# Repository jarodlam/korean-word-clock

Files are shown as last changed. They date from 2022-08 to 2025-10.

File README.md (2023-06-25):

# Korean word clock
A wall-mounted clock that reads out the current time in Korean.

## Bill of materials
* Raspberry Pi Pico
    * [Core Electronics](https://core-electronics.com.au/raspberry-pi-pico.html)
* Pimoroni RV3028 Breakout
    * [Core Electronics](https://core-electronics.com.au/pimoroni-rv3028-real-time-clock-rtc-breakout.html)
* Adafruit USB-C Breakout
    * [Core Electronics](https://core-electronics.com.au/adafruit-usb-c-breakout-board-downstream-connection.html)
* 1000 uF electrolytic capacitor
    * [Core Electronics](https://core-electronics.com.au/electrolytic-decoupling-capacitors-1000uf-25v.html)
* 1N4733A 5.1 V Zener diode
    * [Core Electronics](https://core-electronics.com.au/zener-diode-5-1v-1w.html)
    * [Jaycar](https://www.jaycar.com.au/5-1v-1n4733-1-watt-zener-diode/p/ZR1403)
* LED 3-pin JST-SM pigtail connectors
    * [Core Electronics](https://core-electronics.com.au/led-strip-pigtail-connector-3-pin.html)
* 12mm momentary push button
    * [Core Electronics](https://core-electronics.com.au/momentary-push-button-switch-12mm-square.html)
    * [Jaycar](https://www.jaycar.com.au/spst-pcb-mount-tactile-switch-round/p/SP0609)

## Translations
Korean | English
------ | -------
한시 | one o'clock
두시 | two o'clock
세시 | three o'clock
네시 | four o'clock
다섯시 | five o'clock
여섯시 | six o'clock
일곱시 | seven o'clock
여덟시 | eight o'clock
아홉시 | nine o'clock
열시 | ten o'clock
열한시 | eleven o'clock
열두시 | twelve o'clock
자정 | midnight
정오 | noon
오분 | five minutes
십분 | ten minutes
이십분 | twenty minutes
삼십분 | thirty minutes
사십분 | forty minutes
오십분 | fifty minutes

## Acknowledgements
* [HangulClock](https://suapapa.github.io/site-hangulclocks/) by Homin Lee
* [Raspberry Pi Pico EAGLE library](https://github.com/Lobo-T/RPI-Pico-Eagle-lib) by Lobo-T
* [pi_pico_neopixel](https://github.com/blaz-r/pi_pico_neopixel) MicroPython library by Blaž Rolih
* [rv3028-python](https://github.com/pimoroni/rv3028-python) MicroPython library by Pimoroni

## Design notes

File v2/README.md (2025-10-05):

# Korean word clock v2
A wall-mounted clock that reads out the current time in Korean.

Change log from v1:
- Uses an ATmega32U4 microcontroller instead of the RP2040. 
- PCB is drawn in KiCad instead of EAGLE.

## Bill of materials
* SparkFun Qwiic Pro Micro
    * [Core Electronics](https://core-electronics.com.au/sparkfun-qwiic-pro-micro-usb-c-atmega32u4.html)
    * [Mouser](https://au.mouser.com/ProductDetail/SparkFun/DEV-15795?qs=vHuUswq2%252BszUNhUhTg0rsg%3D%3D)
* Pimoroni RV3028 Breakout
    * [Core Electronics](https://core-electronics.com.au/pimoroni-rv3028-real-time-clock-rtc-breakout.html)
    * [Mouser](https://au.mouser.com/ProductDetail/Pimoroni/PIM449?qs=GedFDFLaBXE4W0MVwPUjCA%3D%3D)
* LED 3-pin JST-SM pigtail connector
    * [Core Electronics](https://core-electronics.com.au/led-strip-pigtail-connector-3-pin.html)
    * [Mouser](https://au.mouser.com/ProductDetail/Adafruit/1663?qs=GURawfaeGuBbzkAfeSrhnA%3D%3D)
* 12mm momentary push buttons
    * [Core Electronics](https://core-electronics.com.au/momentary-push-button-switch-12mm-square.html)
    * [Mouser](https://au.mouser.com/ProductDetail/SparkFun/COM-09190?qs=WyAARYrbSnYmfgv9mXV0oQ%3D%3D)
    * [Jaycar](https://www.jaycar.com.au/spst-pcb-mount-tactile-switch-round/p/SP0609)
* 4.7k resistors 1.6x3.6 mm
    * [Mouser](https://au.mouser.com/ProductDetail/YAGEO/MFR25SFTF52-4K7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)

## Software

Requirements:

- [PlatformIO](https://platformio.org/)

Usage (run from `src/` directory with `platformio.ini`:

```sh
# Build
$ pio run

# Upload
$ pio run -t upload

# Generate clangd compile_commands.json for LSP
$ pio run -t compiledb -e sparkfun_promicro16

# Clean build files
$ pio run -t clean

# Run local tests
$ pio test -e native

# View serial monitor
$ pio device monitor
```

## Translations
Korean | English
------ | -------
한시 | one o'clock
두시 | two o'clock
세시 | three o'clock
네시 | four o'clock
다섯시 | five o'clock
여섯시 | six o'clock
일곱시 | seven o'clock
여덟시 | eight o'clock
아홉시 | nine o'clock
열시 | ten o'clock
열한시 | eleven o'clock
열두시 | twelve o'clock
자정 | midnight
정오 | noon
오분 | five minutes
십분 | ten minutes
이십분 | twenty minutes
삼십분 | thirty minutes
사십분 | forty minutes
오십분 | fifty minutes

## Acknowledgements and references
* [HangulClock](https://suapapa.github.io/site-hangulclocks/) by Homin Lee
* [Adafruit NeoPixel library](https://github.com/adafruit/Adafruit_NeoPixel)
* [SparkFun KiCad Libraries](https://github.com/sparkfun/SparkFun-KiCad-Libraries)

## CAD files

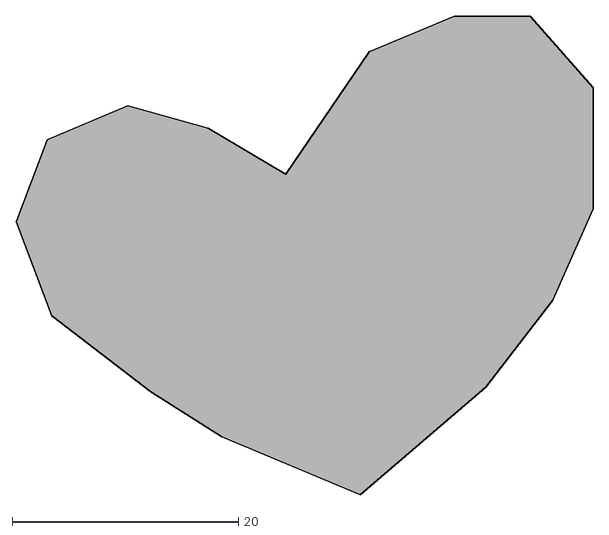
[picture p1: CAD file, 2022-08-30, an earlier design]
v1/pcb/heart.dxf
51.0 x 42.3

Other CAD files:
v1/cad/main.scad

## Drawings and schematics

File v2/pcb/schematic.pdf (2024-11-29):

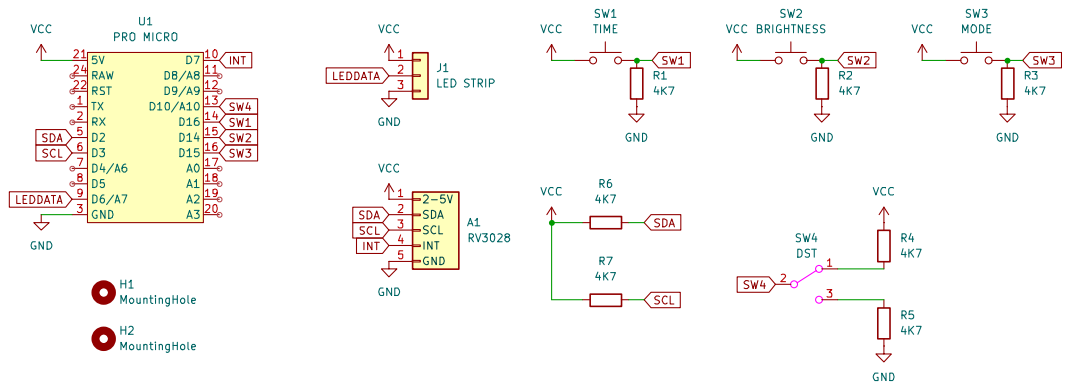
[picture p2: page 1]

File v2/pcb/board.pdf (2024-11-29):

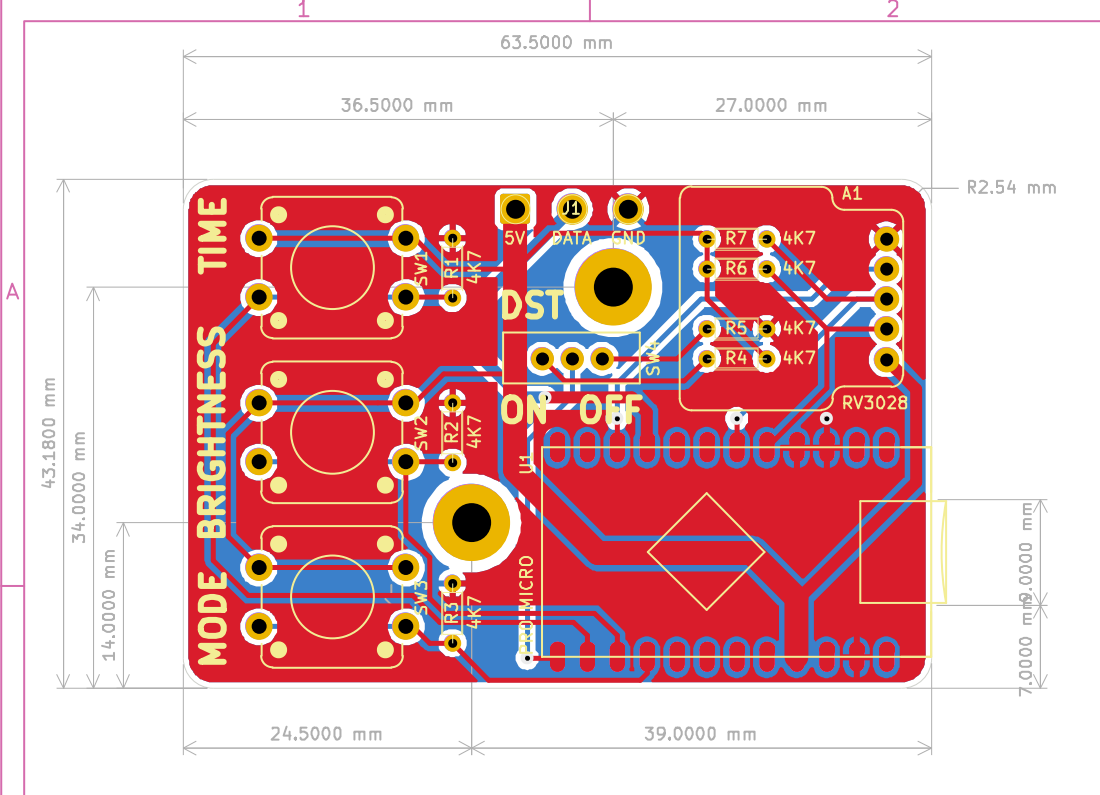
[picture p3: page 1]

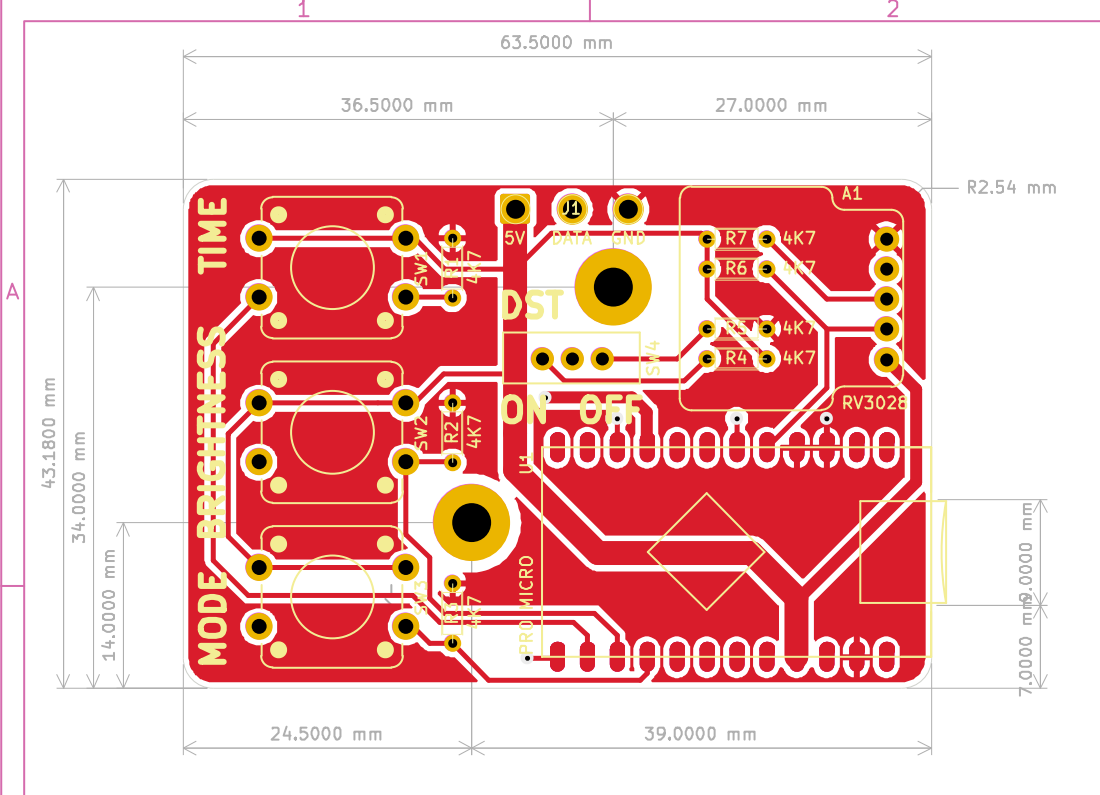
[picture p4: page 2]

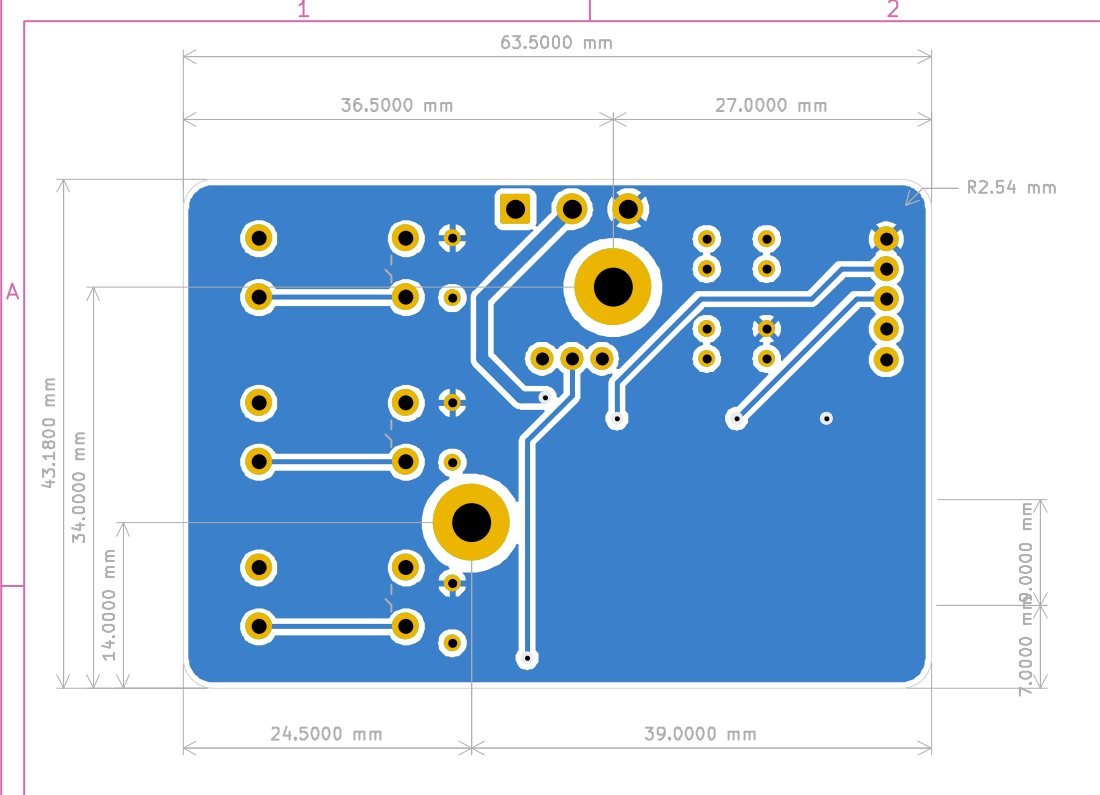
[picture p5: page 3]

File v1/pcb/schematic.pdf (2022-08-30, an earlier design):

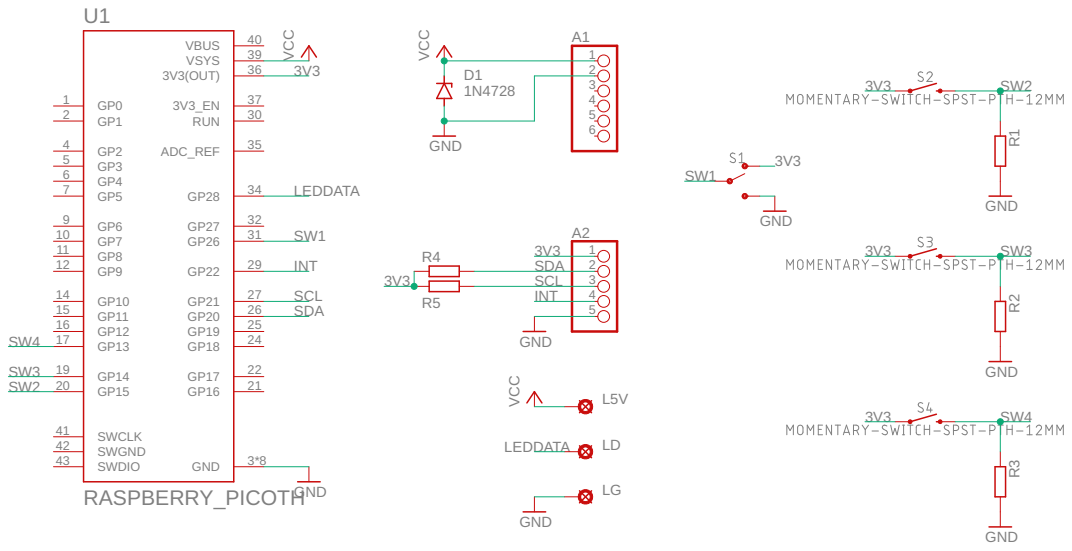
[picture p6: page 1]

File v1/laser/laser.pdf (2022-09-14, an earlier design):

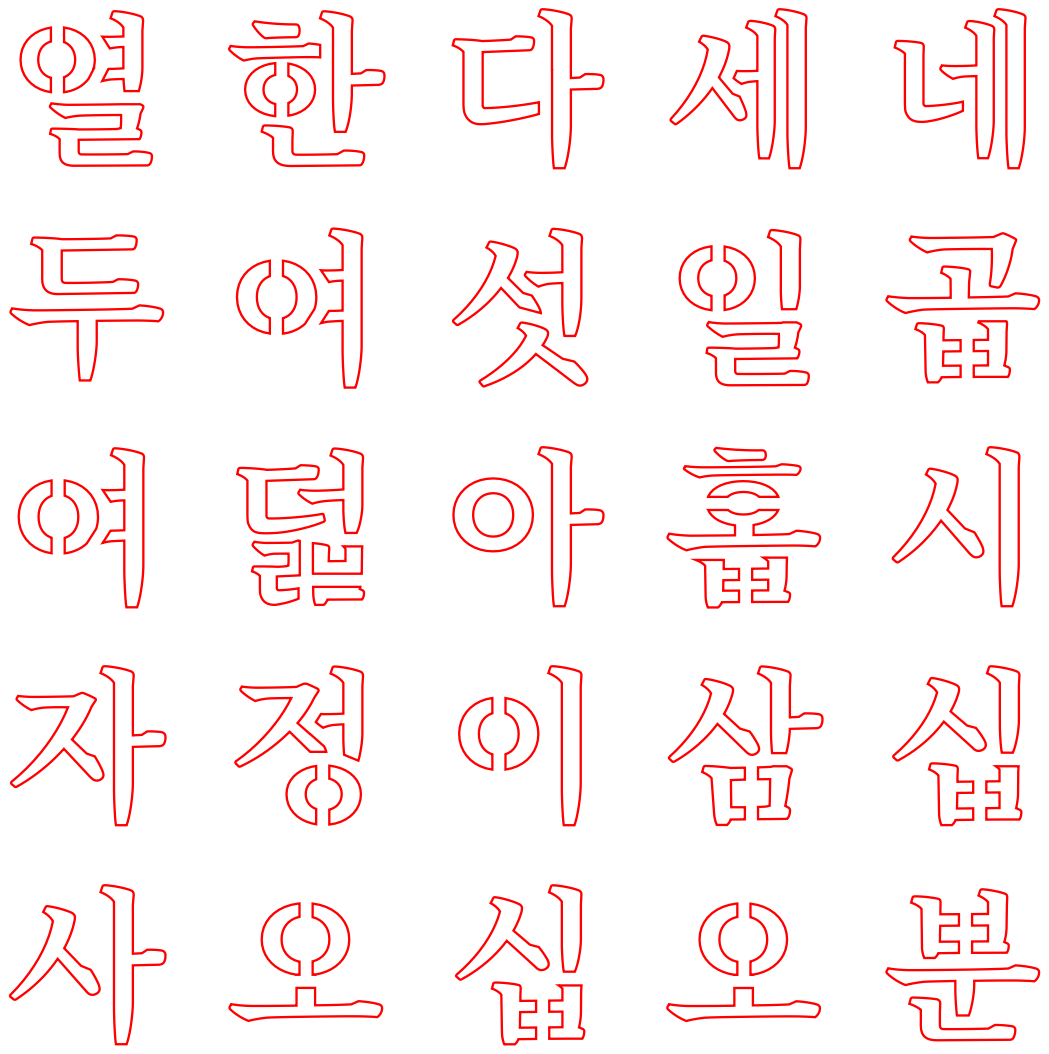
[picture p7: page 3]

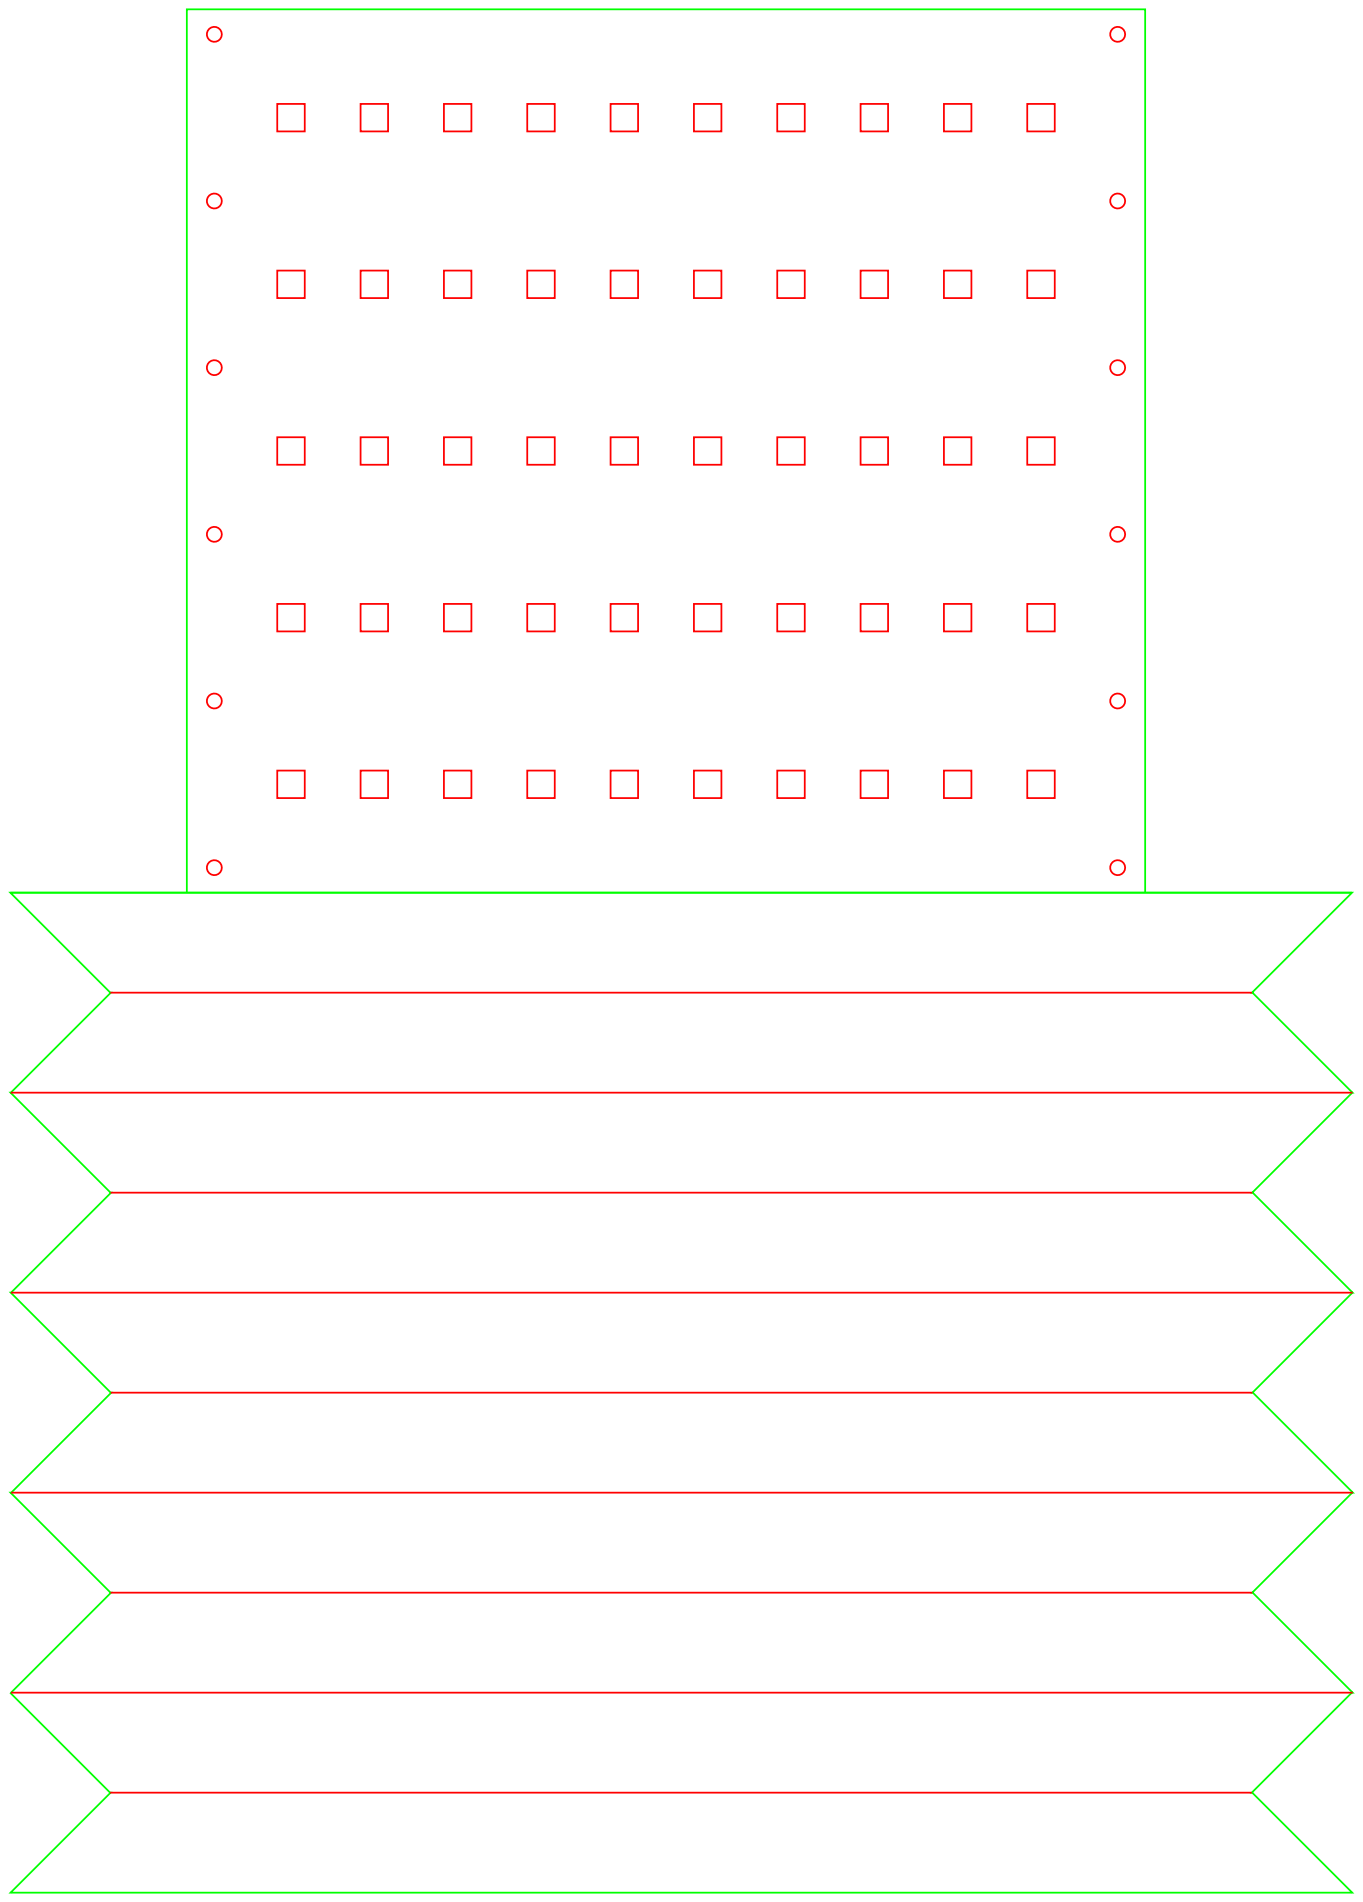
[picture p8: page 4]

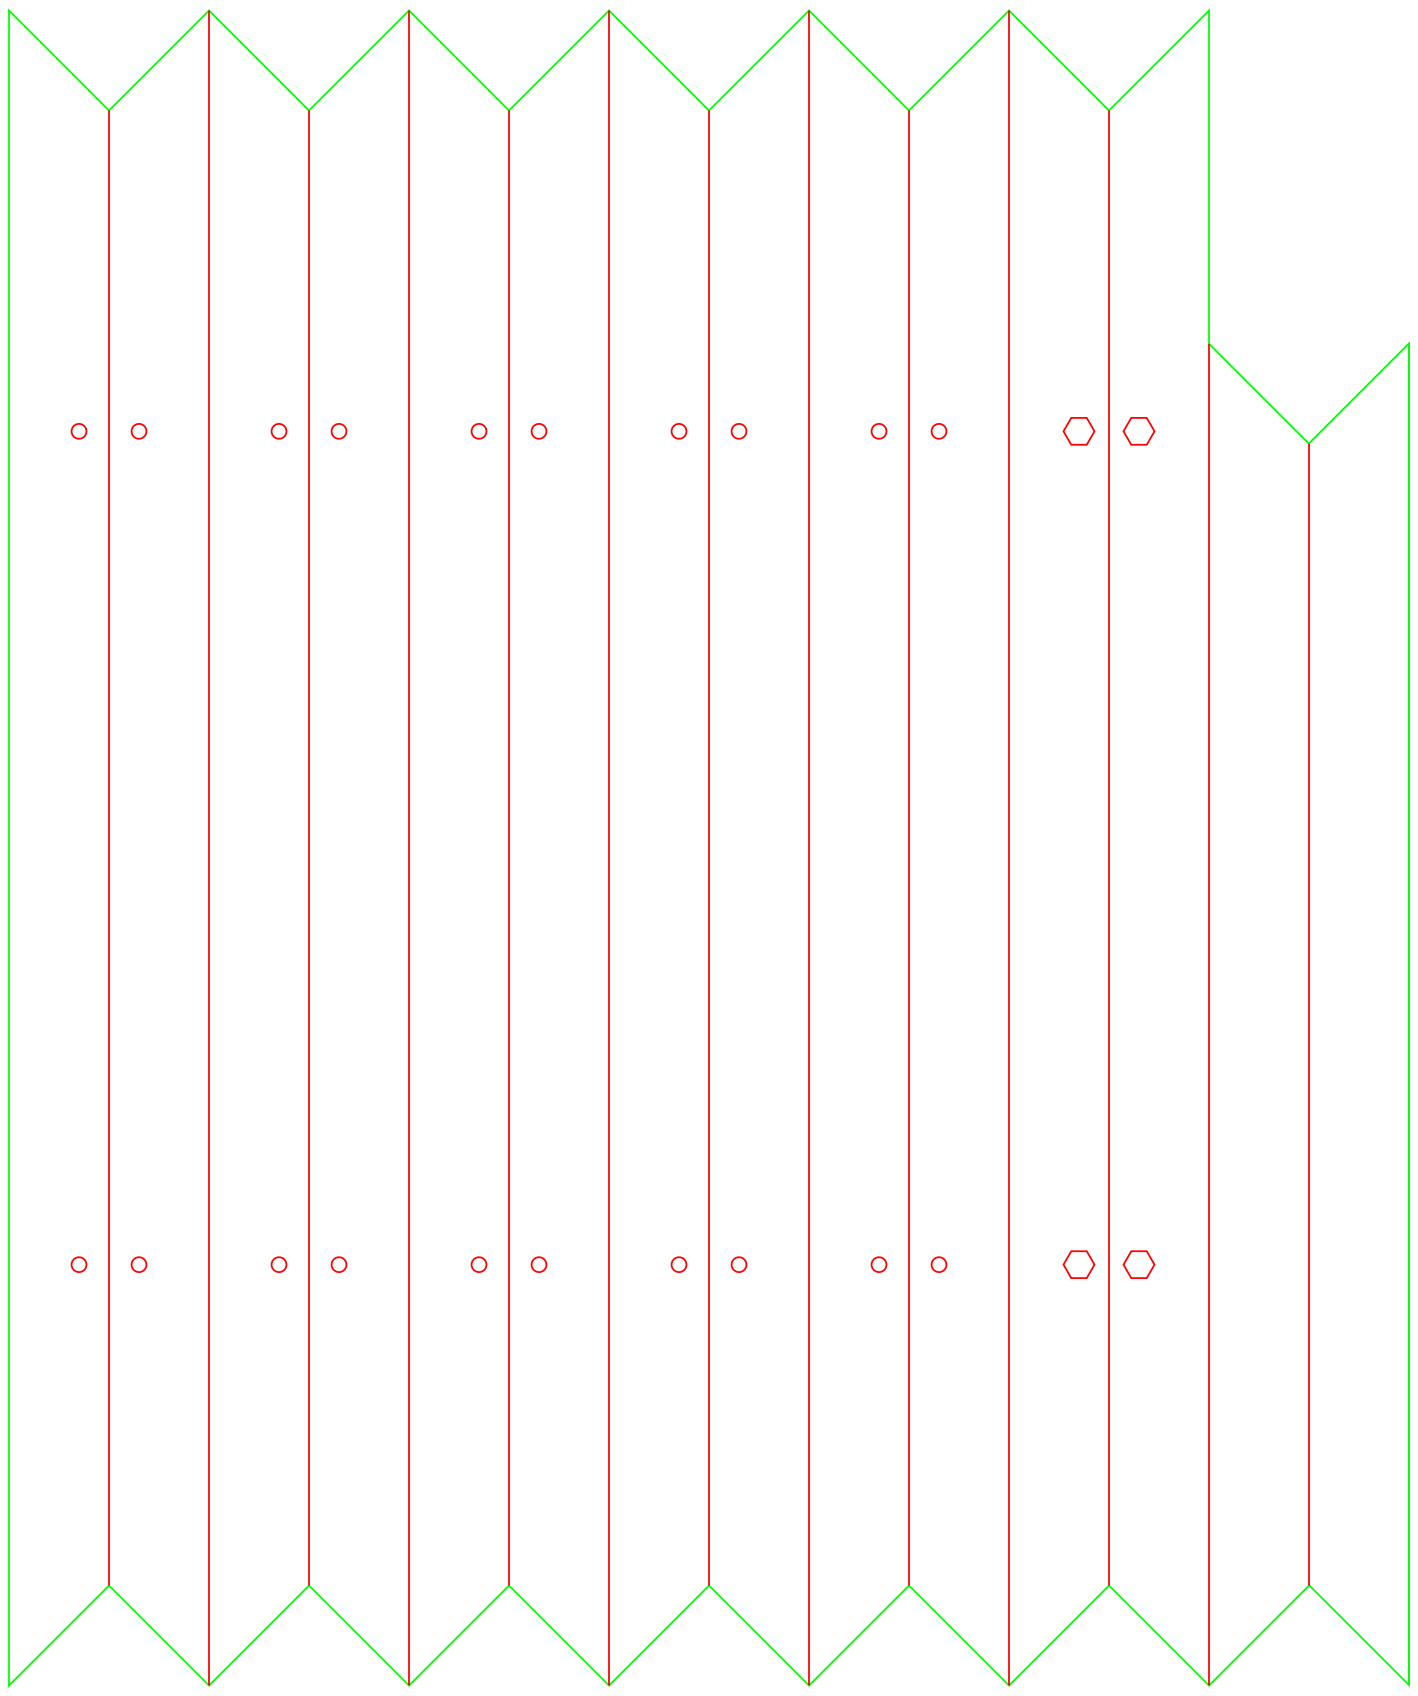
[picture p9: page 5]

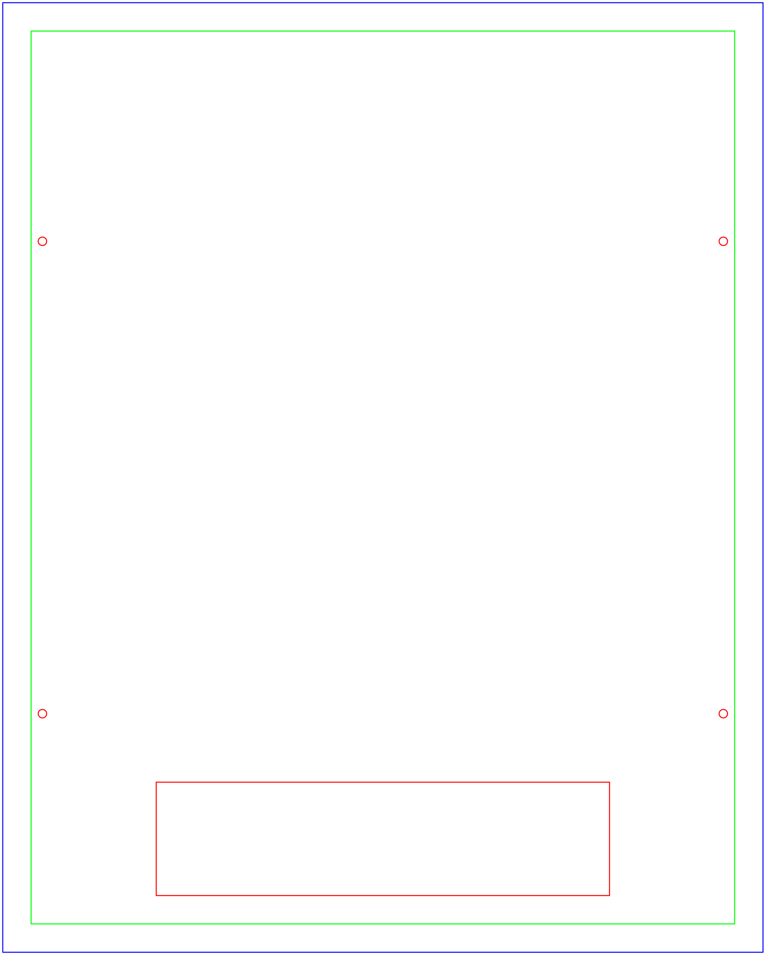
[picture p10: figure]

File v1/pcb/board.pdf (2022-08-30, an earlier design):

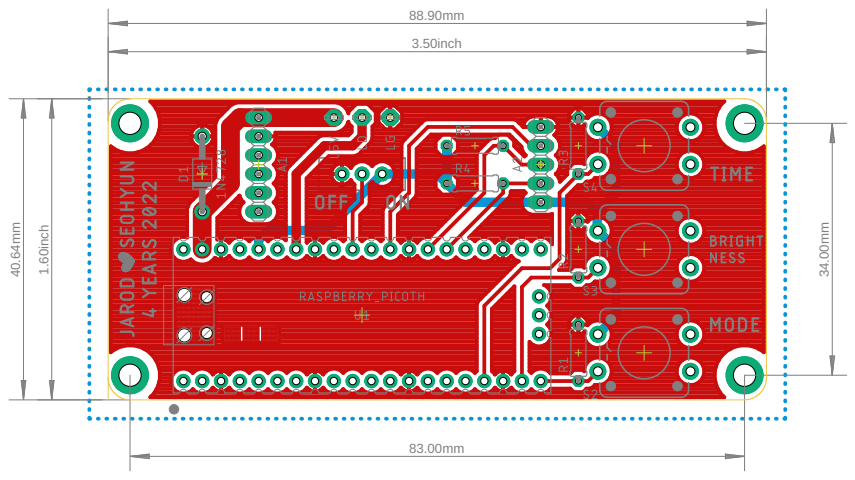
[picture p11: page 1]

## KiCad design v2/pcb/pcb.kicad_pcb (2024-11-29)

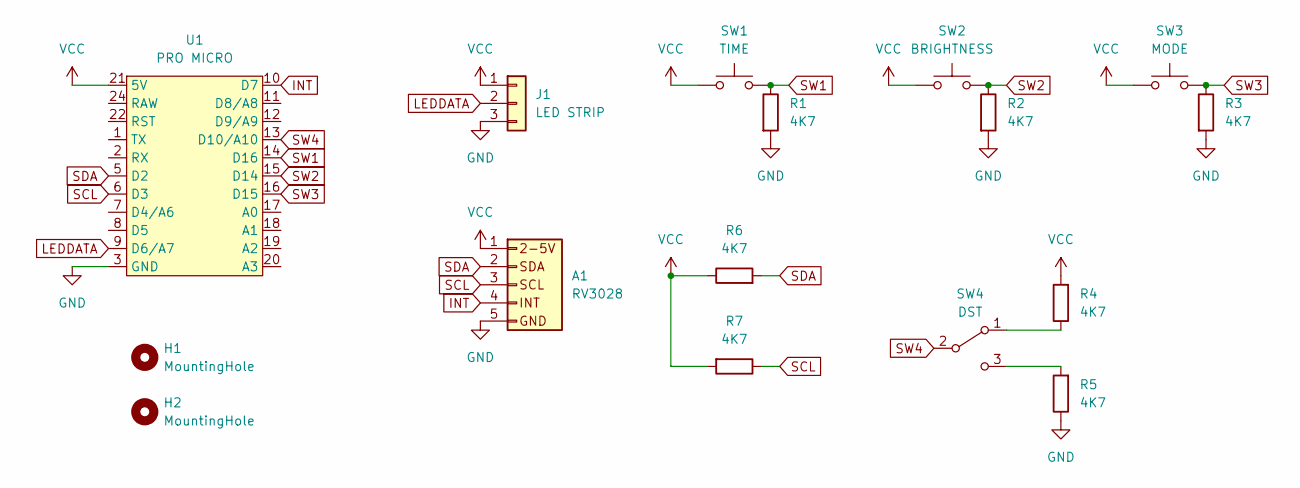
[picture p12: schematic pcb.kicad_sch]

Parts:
A1: RV3028; Pimoroni_RV3028_Breakout
H1, H2: MountingHole; MountingHole_3.2mm_M3_Pad
J1: LED STRIP; SolderWire-0.75sqmm_1x03_P4.8mm_D1.25mm_OD2.3mm
R1, R2, R3, R4, R5, R6, R7: 4K7; R_Axial_DIN0204_L3.6mm_D1.6mm_P5.08mm_Horizontal
SW1: TIME; Push_PTH_12x12mm; Mfg Part# EG4904TR-ND
SW2: BRIGHTNESS; Push_PTH_12x12mm; Mfg Part# EG4904TR-ND
SW3: MODE; Push_PTH_12x12mm; Mfg Part# EG4904TR-ND
SW4: DST; Slide_SPDT_PTH_11.6x4.0mm
U1: PRO MICRO; ProMicroC

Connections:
GND: A1.5, J1.3, R1.2, R2.2, R3.2, R5.1, U1.3 (GND), U1.4 (GND), U1.23 (GND)
INT: A1.4, U1.10 (D7)
LEDDATA: J1.2, U1.9 (D6/A7)
unnamed: R4.1, SW4.1 (A)
unnamed: R5.2, SW4.3 (C)
SCL: A1.3, R7.1, U1.6 (D3)
SDA: A1.2, R6.2, U1.5 (D2)
SW1: R1.1, SW1.2, U1.14 (D16)
SW2: R2.1, SW2.2, U1.15 (D14)
SW3: R3.1, SW3.2, U1.16 (D15)
SW4: SW4.2 (B), U1.13 (D10/A10)
VCC: A1.1, J1.1, R4.2, R6.1, R7.2, SW1.1, SW2.1, SW3.1, U1.21 (5V)

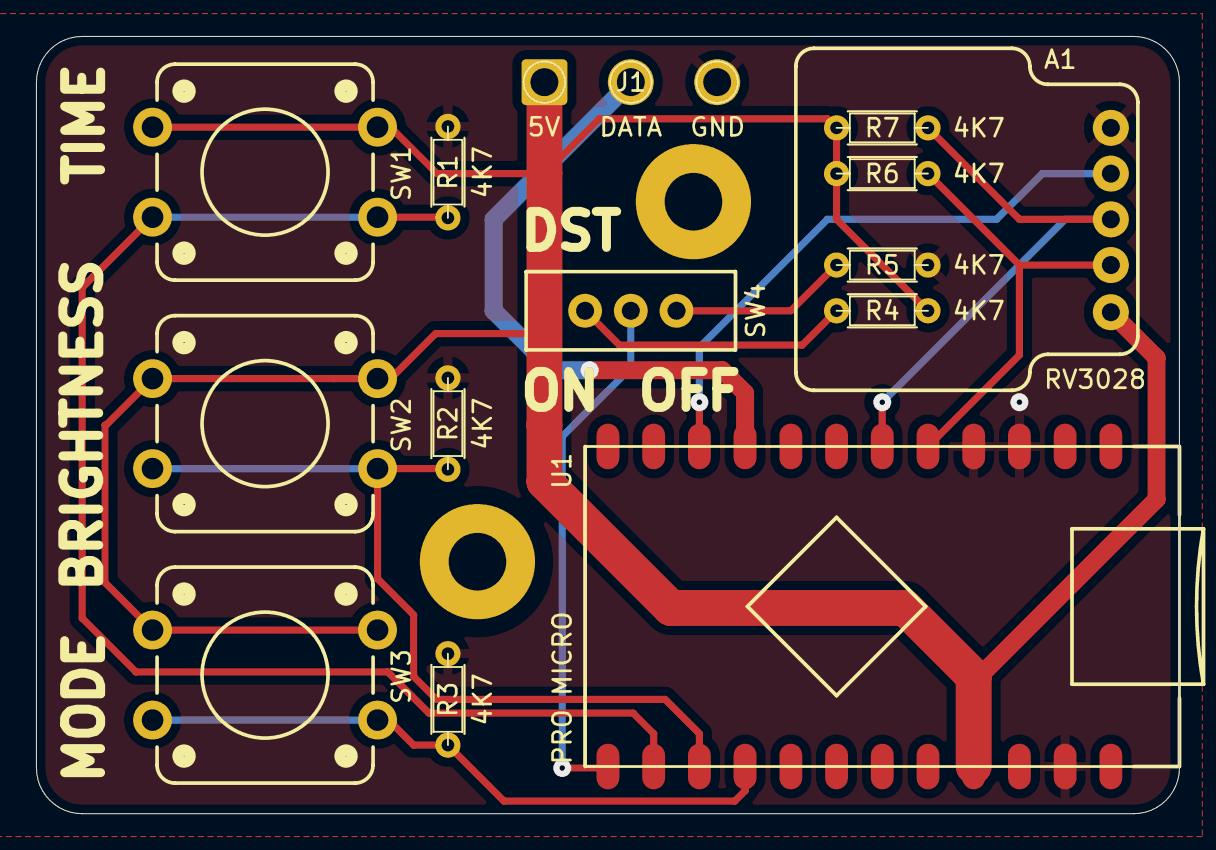
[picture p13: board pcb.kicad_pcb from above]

Board: 2 copper layers, 63.5 x 43.2 mm, 16 parts (0 on the bottom side), 12 nets.

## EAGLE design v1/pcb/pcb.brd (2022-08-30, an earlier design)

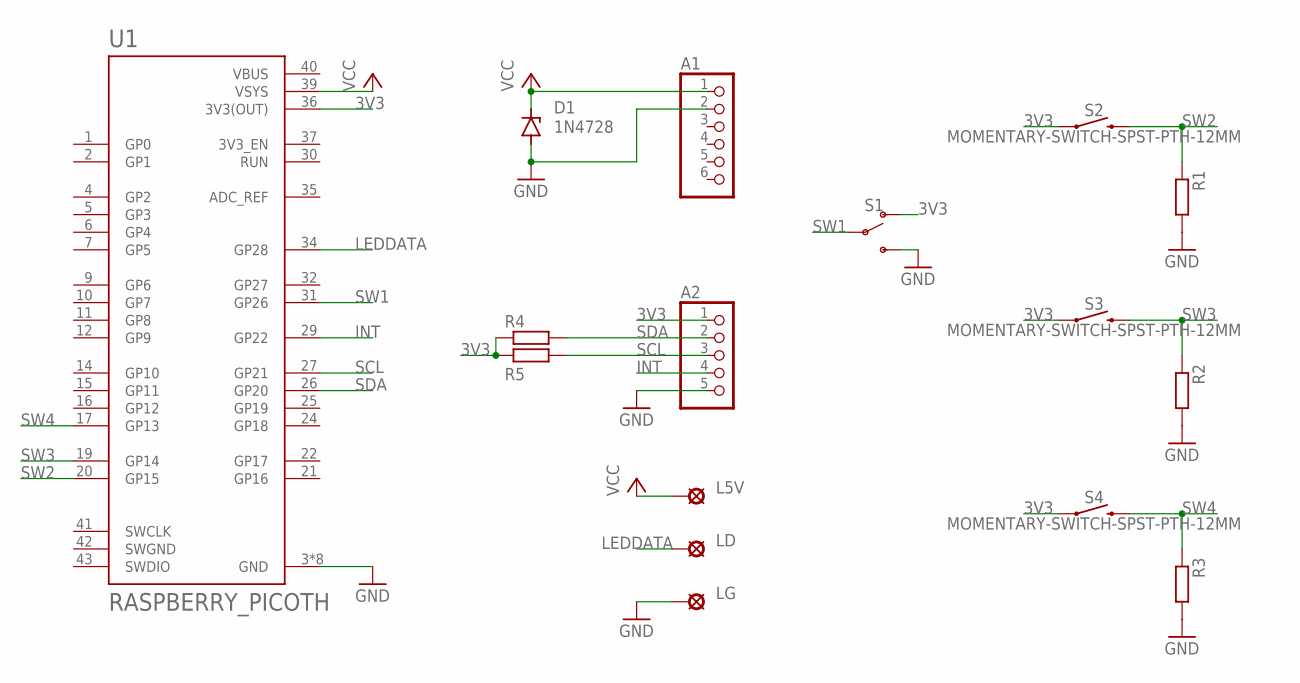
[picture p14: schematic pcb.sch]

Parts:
A1: PINHD-1X6; 1X06
A2: PINHD-1X5; 1X05
D1: 1N4728; DO41Z10
L5V: LSP10
LD: LSP10
LG: LSP10
R1, R2, R3, R4, R5: R-EU_0207/7; 0207/7
S1: SWITCH-SPDT-PTH-11.6X4.0MM-LOCK; SWITCH_SPDT_PTH_11.6X4.0MM_LOCK
S2, S3, S4: MOMENTARY-SWITCH-SPST-PTH-12MM; TACTILE_SWITCH_PTH_12MM
U1: RASPBERRY_PICOTH; PICO-PKG-TH

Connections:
3V3: A2.1, R4.1, R5.1, S1.1 (O), S2.1, S3.1, S4.1, U1.36 (3V3(OUT))
GND: A1.2, A2.5, D1.A, LG.MP, R1.2, R2.2, R3.2, S1.3 (S), U1.3 (GND), U1.8 (GND), U1.13 (GND), U1.18 (GND), U1.23 (GND), U1.28 (GND), U1.33 (GND), U1.38 (GND)
INT: A2.4, U1.29 (GP22)
LEDDATA: LD.MP, U1.34 (GP28)
SCL: A2.3, R5.2, U1.27 (GP21)
SDA: A2.2, R4.2, U1.26 (GP20)
SW1: S1.2, U1.31 (GP26)
SW2: R1.1, S2.3 (2), U1.20 (GP15)
SW3: R2.1, S3.3 (2), U1.19 (GP14)
SW4: R3.1, S4.3 (2), U1.17 (GP13)
SWGND: U1.42 (SWGND)
VBUS: U1.40 (VBUS)
VCC: A1.1, D1.C, L5V.MP, U1.39 (VSYS)

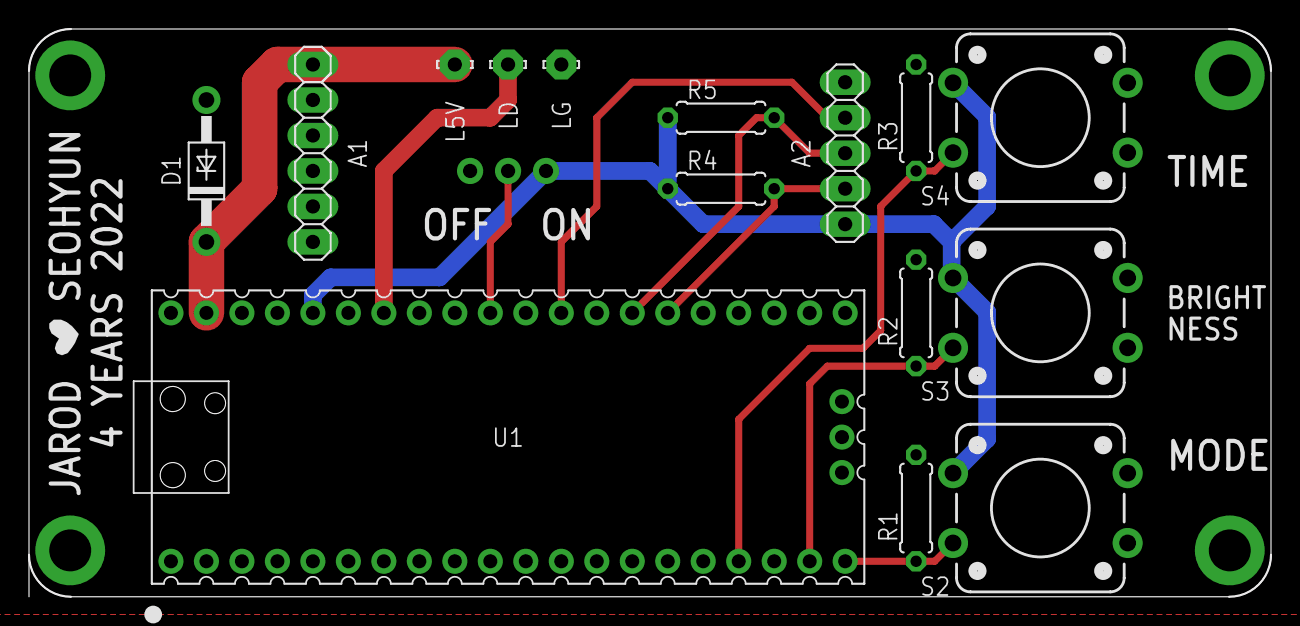
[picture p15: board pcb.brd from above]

Board: 2 copper layers, 88.9 x 40.6 mm, 16 parts (1 on the bottom side), 11 nets.

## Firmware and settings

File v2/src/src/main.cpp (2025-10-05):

#include <Button.h>
#include <Sk6812LedMatrix.h>
#include <Rv3028Clock.h>
#include <KoreanClockFace.h>

/*
 * Uncomment to set the time.
 * After setting time, comment out and re-upload.
 *
 * Format is:
 *   second, minute, hour (24h), weekday (0=Sunday), day, month, year
 */
// #define SET_TIME 00, 40, 10, 0, 15, 02, 2025

/*
 * Config
 */
#define PIN_LEDDATA 6
#define PIN_SW1 16
#define PIN_SW2 14
#define PIN_SW3 15
#define PIN_SW4 10
#define MATRIX_LEDS_PER_CELL 2

/*
 * Globals
 */
Sk6812LedMatrix matrix{ KOREAN_CLOCK_FACE_WIDTH, KOREAN_CLOCK_FACE_HEIGHT, MATRIX_LEDS_PER_CELL, PIN_LEDDATA };
Rv3028Clock rtc{};
KoreanClockFace clockFace{ matrix };

void setup() {
  Serial.begin(9600);
  Wire.begin();

  rtc.begin();
  matrix.begin();
  // clockFace.begin();
  // matrix.setBrightness(255);

#ifdef SET_TIME
  DateTime newTime = DateTime{ SET_TIME };
  rtc.setDateTime(newTime);
  while (true) {  // Disable device in set time mode
  }
#endif
}

void loop() {
  DateTime dt = rtc.readDateTime();

  Serial.print(dt.hour);
  Serial.print(":");
  Serial.print(dt.minute);
  Serial.print(":");
  Serial.print(dt.second);
  Serial.println();

  clockFace.update(dt);
  clockFace.show();

  delay(10);
}

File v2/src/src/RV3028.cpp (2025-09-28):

#include "RV3028.h"

RV3028::RV3028(uint8_t addr) : addr(addr) {}

void RV3028::begin() {
  Wire.begin();
  setBatterySwitchoverMode(RV3028_DIRECT_SWITCHING_MODE);
}

DateTime RV3028::readDateTime() {
  /*
  Read the following registers:
  0x00: second
  0x01: minute
  0x02: hour
  0x03: weekday
  0x04: day
  0x05: month
  0x06: year
  */
  uint8_t encoded[7] = {0};
  i2cRead(RV3028_REG_SECONDS, encoded, 7);

  // Decode each value from BCD to regular int
  uint8_t decoded[7];
  for (int i = 0; i < 7; i++) {
    decoded[i] = decodeBcd(encoded[i]);
  }

  return DateTime{
      decoded[0],
      decoded[1],
      decoded[2],
      decoded[3],
      decoded[4],
      decoded[5],
      decoded[6] + (uint16_t)2000, // only last two year digits are stored
  };
}

void RV3028::setDateTime(DateTime dt) {
  // Encode each value from regular int to BCD
  uint8_t encoded[7] = {
      encodeBcd(dt.second),     encodeBcd(dt.minute), encodeBcd(dt.hour),
      encodeBcd(dt.weekday),    encodeBcd(dt.day),    encodeBcd(dt.month),
      encodeBcd(dt.year % 100),
  };

  /*
  Write to the following registers:
  0x00: second
  0x01: minute
  0x02: hour
  0x03: weekday
  0x04: day
  0x05: month
  0x06: year
  */
  i2cWrite(RV3028_REG_SECONDS, encoded, 7);
}

uint8_t RV3028::i2cRead(uint8_t reg) {
  Wire.beginTransmission(addr);
  Wire.write(reg);
  Wire.endTransmission(false);

  Wire.requestFrom(addr, (uint8_t)1);
  if (Wire.available()) {
    return Wire.read();
  } else {
    return 0;
  }
}

void RV3028::i2cRead(uint8_t reg, uint8_t *buf, size_t len) {
  Wire.beginTransmission(addr);
  Wire.write(reg);
  Wire.endTransmission(false);

  Wire.requestFrom(addr, len);
  for (uint16_t i = 0; i < len; i++) {
    if (Wire.available() <= 0) {
      break;
    }
    buf[i] = Wire.read();
  }
}

void RV3028::i2cWrite(uint8_t reg, uint8_t value) {
  Wire.beginTransmission(addr);
  Wire.write(reg);
  Wire.write(value);
  Wire.endTransmission();
}

void RV3028::i2cWrite(uint8_t reg, uint8_t *buf, size_t len) {
  Wire.beginTransmission(addr);
  Wire.write(reg);
  Wire.write(buf, len);
  Wire.endTransmission();
}

bool RV3028::i2cReadBit(uint8_t reg, uint8_t bitPos) {
  uint8_t regVal = i2cRead(reg);
  return (regVal >> bitPos) & 1;
}

void RV3028::i2cWriteBit(uint8_t reg, uint8_t bitPos, bool bitVal) {
  uint8_t regVal = i2cRead(reg);
  if (bitVal) {
    regVal = regVal | (1 << bitPos);
  } else {
    regVal = regVal & ~(1 << bitPos);
  }
  i2cWrite(reg, regVal);
}

uint8_t RV3028::eepromRead(uint8_t eepromAddr) {
  /*
  Before starting to read a byte in the EEPROM,
  the auto refresh of the registers from the EEPROM has to be disabled
  by writing 1 into the EERD control bit.
  */
  i2cWriteBit(RV3028_REG_CONTROL1, RV3028_POS_CONTROL1_EERD, true);
  eepromWaitBusy();

  /*
  In order to read a single byte from the EEPROM,
  the address to be read is entered in the EEADDR register,
  then the command 00h is written in the EECMD register,
  then the second command 22h is written in the EECMD register
  and the resulting byte can be read from the EEDATA register.
  */
  i2cWrite(RV3028_REG_EEADDR, eepromAddr);
  i2cWrite(RV3028_REG_EECMD, (uint8_t)0x00);
  i2cWrite(RV3028_REG_EECMD, (uint8_t)0x22);
  eepromWaitBusy();
  uint8_t value = i2cRead(RV3028_REG_EEDATA);

  /*
  When the transfer is finished (EEbusy = 0),
  the user can enable again the auto refresh of the registers
  by writing 0 into the EERD bit in the Control 1 register.
  */
  eepromWaitBusy();
  i2cWriteBit(RV3028_REG_CONTROL1, RV3028_POS_CONTROL1_EERD, false);

  return value;
}

void RV3028::eepromWrite(uint8_t eepromAddr, uint8_t value) {
  /*
  Before starting to change data stored in the EEPROM,
  the auto refresh of the registers from the EEPROM has to be disabled
  by writing 1 into the EERD control bit.
  */
  i2cWriteBit(RV3028_REG_CONTROL1, RV3028_POS_CONTROL1_EERD, true);
  eepromWaitBusy();

  /*
  In order to write a single byte to the EEPROM,
  the address to which the data must be written is entered in the EEADDR
  register and the data to be written is entered in the EEDATA register, then
  the command 00h is written in the EECMD register, then a second command 21h is
  written in the EECMD register to start the EEPROM write.
  */
  i2cWrite(RV3028_REG_EEADDR, eepromAddr);
  i2cWrite(RV3028_REG_EEDATA, value);
  i2cWrite(RV3028_REG_EECMD, (uint8_t)0x00);
  i2cWrite(RV3028_REG_EECMD, (uint8_t)0x21);

  /*
  When the transfer is finished (EEbusy = 0),
  the user can enable again the auto refresh of the registers
  by writing 0 into the EERD bit in the Control 1 register.
  */
  eepromWaitBusy();
  i2cWriteBit(RV3028_REG_CONTROL1, RV3028_POS_CONTROL1_EERD, false);
}

void RV3028::eepromWaitBusy() {
  /*
  Wait until the EEBUSY bit is cleared
  before continuing an EEPROM read or write operation.
  */
  while (true) {
    bool busy = i2cReadBit(RV3028_REG_STATUS, RV3028_POS_STATUS_EEBUSY);
    if (!busy) {
      break;
    }
  }
}

void RV3028::setBatterySwitchoverMode(uint8_t mode) {
  // Read the current value of the EEPROM Backup register
  uint8_t value = eepromRead(RV3028_REG_BACKUP);

  // Clear the BSM and FEDE (Fast Edge Detection Enable) bits
  value = value &
          ~((1 << RV3028_POS_BACKUP_BSM) & (1 << (RV3028_POS_BACKUP_BSM + 1)) &
            (1 << RV3028_POS_BACKUP_FEDE));

  // Write the BSM bits
  value = value | ((mode & 0x3) << RV3028_POS_BACKUP_BSM);

  // Set FEDE to 1, required for automatic battery switchover
  if (mode != RV3028_SWITCHOVER_DISABLED) {
    value = value | (1 << RV3028_POS_BACKUP_FEDE);
  }

  // Write the updated config to the EEPROM Backup register
  eepromWrite(RV3028_REG_BACKUP, value);
}

uint8_t RV3028::encodeBcd(uint8_t normalInt) {
  uint8_t lower = normalInt % 10;
  uint8_t upper = (normalInt / 10) % 10;
  return lower + (upper << 4);
}

uint8_t RV3028::decodeBcd(uint8_t bcdInt) {
  uint8_t lower = bcdInt & 0x0F;
  uint8_t upper = (bcdInt & 0xF0) >> 4;
  return lower + (upper * 10);
}

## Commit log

2022-06-14 [CAD] CAD work in progress
    [main.scad]
2022-06-14 [CAD] Layer 2 and 3
    [main.scad]
2022-06-14 [CAD] Most layers done
    [main.scad]
2022-07-05 [PCB] Initial commit for PCB
    [pcb.brd, pcb.sch]
2022-08-25 [CAD] Finish 3D design
    [main.scad]
2022-08-27 [DOC] Updated BOM
2022-08-29 [PCB] Finished design subject to testing
    [pcb.brd, pcb.sch]
2022-08-29 [DOC] Translations and updated BOM
2022-08-30 [PCB] Sent off for manufacturing
    [heart.dxf, pcb.brd, pcb.sch]
2022-08-30 [CAD] Cutout size for PCB
    [main.scad]
2022-09-14 [CAD] Mostly final design, need to fix front grid spacing
    [main.scad]
2022-09-14 [LASER] Start work on laser layout
2022-09-14 [CAD] Fix grid spacing
    [main.scad]
2022-09-14 [LASER] Final layout
2022-09-25 [SRC] Button hook up and fast-forwarding
2022-09-25 [SRC] Move ButtonInput to a separate file
2022-10-04 [SRC] Switch daylight savings on/off using switch
2024-11-22 [CHORE] Add v2
    [heart.dxf, main.scad, pcb.brd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]
2024-11-22 [PCB] Start v2 PCB
    [pcb.kicad_pcb, pcb.kicad_sch]
2024-11-22 [DOC] Add additional BOM
2024-11-27 [PCB] New PCB mostly complete
    [pcb.kicad_pcb, pcb.kicad_sch]
2024-11-29 [DOC] Correct resistor
2024-11-29 [PCB] Final design and gerber
    [pcb-B_Cu.gbr, pcb-B_Mask.gbr, pcb-B_Paste.gbr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]
2025-01-11 [SRC] Button implementation
2025-03-29 [SRC] LED matrix code

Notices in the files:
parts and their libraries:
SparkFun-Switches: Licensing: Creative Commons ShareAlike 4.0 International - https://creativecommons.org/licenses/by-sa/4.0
